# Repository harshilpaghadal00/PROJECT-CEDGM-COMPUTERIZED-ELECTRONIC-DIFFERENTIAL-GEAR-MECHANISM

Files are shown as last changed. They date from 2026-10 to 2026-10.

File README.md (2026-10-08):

# PROJECT CEDGM : COMPUTERIZED ELECTRONIC DIFFERENTIAL GEAR MECHANISM



Welcome to the **PROJECT CEDGM : COMPUTERIZED ELECTRONIC DIFFERENTIAL GEAR MECHANISM** project. This repository contains the complete suite of mechanical designs, electronic documentation, and firmware required to build, assemble, and run an Arduino-controlled Differential Gear Mechanism.

## Project Structure

The project is divided into three main subsystems:

### 1. Mechanical System (`01 - PROJECT CEDGM : COMPUTERIZED ELECTRONIC DIFFERENTIAL GEAR MECHANISM - MECHANICAL SYSTEM`)

Contains the CAD models for 3D printing and modification. Files are provided in `.f3d` (Fusion 360), `.step` (Standard 3D CAD), and `.stl` (Ready for 3D Printing) formats.

* **01 - Standard External Involute Miter Bevel Gear**
* **02 - T-Shape Standard External Involute Miter Bevel Gear Connector**
* **03 - 28BYJ-48 Stepper Motor (Mockup/Mount)**
* **04 - Primary Support Mechanism (Right Side)**
* **05 - Primary Support Mechanism (Left Side)**
* **06 - Differential Gear Mechanism** (Full assembly)
* **07 - Differential Gear Mechanism Base**

### 2. Electronic System (`02 - PROJECT CEDGM : COMPUTERIZED ELECTRONIC DIFFERENTIAL GEAR MECHANISM - ELECTRONIC SYSTEM`)

Contains all necessary datasheets and wiring documentation to safely build the circuit.

* **01 - 28BYJ-48 Stepper Motor Data Sheet**
* **02 - ULN2003 Stepper Motor Driver Data Sheet**
* **03 - Arduino UNO Data Sheet**
* **04 - Power Supply & Pin Configuration Documentation**

### 3. Embedded System & Software (`03 - PROJECT CEDGM : COMPUTERIZED ELECTRONIC DIFFERENTIAL GEAR MECHANISM - EMBEDDED SYSTEM & SOFTWARE`)

Contains the logic and control code for the microcontroller.

* **FINAL_FIRMWARE.ino**: The main Arduino sketch to upload to the board.
* **FIRMWARE FLOW.cpp**: A C++ file detailing the logic flow and algorithm of the firmware.

---

## 🛠️ Hardware Requirements

To build this project physically, you will need:

* 1x **Arduino UNO** (or compatible microcontroller)
* 1x (or more, as required) **28BYJ-48 Stepper Motor**
* 1x **ULN2003 Stepper Motor Driver Board**
* Appropriate **Power Supply** (Refer to the Power Supply Documentation in the Electronics folder)
* Jumper wires
* A 3D Printer and filament (PLA/PETG recommended) to print the mechanical parts.

---

## 🚀 Getting Started Guide

### Step 1: Mechanical Assembly

1. Locate the `.stl` files in the `01 - PROJECT CEDGM : COMPUTERIZED ELECTRONIC DIFFERENTIAL GEAR MECHANISM - MECHANICAL SYSTEM` folder.
2. Slice and 3D print the Base, Left/Right Support Mechanisms, Bevel Gears, and Connectors.
3. Assemble the printed parts. Use the Fusion 360 (`.f3d` or `.f3z`) files as a visual reference for how the components fit together.
4. Mount the **28BYJ-48 Stepper Motor** into the designated slot on the support mechanism.

### Step 2: Electronics Wiring

1. Connect the **28BYJ-48 Stepper Motor** to the **ULN2003 Driver Board**.
2. Open `04 - POWER SUPPLY & PIN CONFIGURATION DOCUMENTATION.pdf` in the Electronics folder to find the exact pin mapping.
3. Wire the ULN2003 Driver Board to the corresponding Digital I/O pins on the **Arduino UNO**.
4. Connect the power supply safely, ensuring the Arduino and the Motors receive appropriate voltage (do not draw stepper motor power directly from the Arduino's 5V pin if under heavy load).
5. Important: Use 5V - 2A Power Supply.

### Step 3: Software Setup & Flashing

1. Download and install the [Arduino IDE](https://www.arduino.cc/en/software).
2. Navigate to `03 - PROJECT CEDGM : COMPUTERIZED ELECTRONIC DIFFERENTIAL GEAR MECHANISM - EMBEDDED SYSTEM & SOFTWARE/FINAL_FIRMWARE/`.
3. Open `FINAL_FIRMWARE.ino` in the Arduino IDE.
4. Connect your Arduino UNO to your computer via USB.
5. In the Arduino IDE, go to **Tools > Board** and select "Arduino Uno".
6. Go to **Tools > Port** and select the appropriate COM port.
7. Click the **Upload** button to flash the firmware to the board.

### Step 4: Execution

Once the upload is complete and power is supplied, the Arduino will begin executing the logic defined in `FIRMWARE FLOW.cpp`, driving the stepper motor and actuating the differential gear mechanism.

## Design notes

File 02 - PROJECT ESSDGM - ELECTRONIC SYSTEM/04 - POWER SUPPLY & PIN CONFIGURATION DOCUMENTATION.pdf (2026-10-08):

From | To | Electronic Value | Description
Regulated DC Supply (+) | Central Star Positive Bus (+) | 5.0VDC (1.0A max) | Main positive DC feed from external supply.
Regulated DC Supply (-) | Central Star Ground Bus (-) | 0V / GND | Master ground return line for the entire system.
Central Star Positive Bus (+) | Decoupling Buffer (+) | 5.0VDC (470 uF || 100 nF) | High-frequency and transient voltage stabilization.
Central Star Ground Bus (-) | Decoupling Buffer (-) | 0V / GND | Return path for decoupling filter network.
Central Star Positive Bus (+) | Arduino UNO Pin +5V | 5.0VDC (~60 mA) | Direct ATmega328P logic board supply rail.
Central Star Ground Bus (-) | Arduino UNO Pin Gorund | 0V / GND | Digital logic reference ground return.
Central Star Positive Bus (+) | ULN2003 #1 Pin + | 5.0VDC (~180 mA max) | Driver 1 motor common and flyback diode power.
Central Star Ground Bus (-) | ULN2003 #1 Pin - | 0V / GND | Driver 1 Darlington emitter ground return.
Central Star Positive Bus (+) | ULN2003 #2 Pin + | 5.0VDC (~180 mA max) | Driver 2 motor common and flyback diode power.

Central Star Ground Bus (-) | ULN2003 #2 Pin - | 0V / GND | Driver 2 Darlington emitter ground return.
ULN2003 #1 Jumper Pin A | ULN2003 #1 Jumper Pin B | 0 Ohm Shunt | Connects +5V to Pin 9 clamp diodes and LEDs.
ULN2003 #2 Jumper Pin A | ULN2003 #2 Jumper Pin B | 0 Ohm Shunt | Connects +5V to Pin 9 clamp diodes and LEDs.
Central Star Positive Bus (+) | 10k Resistor Lead 1 | 5.0VDC | Bias source for hardware interrupt pull-up.
10k Resistor Lead 2 | Arduino UNO Pin D2 (INT0) | 5.0VDC / 10 kOhm | Holds interrupt pin HIGH when the button is open.
Arduino UNO Pin D2 | Push Button Terminal 1 | 5.0V / 0V Logic | Routes active-LOW trigger on button press.
Push Button Terminal 2 | Central Star Ground Bus (-) | 0V / GND | Ground reference completing switch closure.
Arduino UNO Pin D2 | 100nF Cap Lead 1 | 100 nF Filter | Shunts mechanical contact bounce to ground.
100nF Cap Lead 2 | Central Star Ground Bus (-) | 0V / GND | Ground return for RC debounce filter network.
Arduino UNO Pin D10 | ULN2003 #1 Pin IN1 | 5.0V Logic (~1.3 mA) | Logic drive for Motor 1 Phase A.
Arduino UNO Pin D3 | ULN2003 #1 Pin IN2 | 5.0V Logic (~1.3 mA) | Logic drive for Motor 1 Phase B.

Arduino UNO Pin D4 | ULN2003 #1 Pin IN3 | 5.0V Logic (~1.3 mA) | Logic drive for Motor 1 Phase C.
Arduino UNO Pin D5 | ULN2003 #1 Pin IN4 | 5.0V Logic (~1.3 mA) | Logic drive for Motor 1 Phase D.
Arduino UNO Pin D6 | ULN2003 #2 Pin IN1 | 5.0V Logic (~1.3 mA) | Logic drive for Motor 2 Phase A.
Arduino UNO Pin D7 | ULN2003 #2 Pin IN2 | 5.0V Logic (~1.3 mA) | Logic drive for Motor 2 Phase B.
Arduino UNO Pin D8 | ULN2003 #2 Pin IN3 | 5.0V Logic (~1.3 mA) | Logic drive for Motor 2 Phase C.
Arduino UNO Pin D9 | ULN2003 #2 Pin IN4 | 5.0V Logic (~1.3 mA) | Logic drive for Motor 2 Phase D.
ATmega328P Pin PB5 (D13) | Built-in LED (LED_BUILTIN) | 5.0V (~5.6 mA) | Onboard PCB trace driving interrupt status LED.
ULN2003 #1 JST Pin 1 | Motor 1 Blue Wire | Switched GND (~85 mA) | Low-side sink for Motor 1 Phase A coil.
ULN2003 #1 JST Pin 2 | Motor 1 Pink Wire | Switched GND (~85 mA) | Low-side sink for Motor 1 Phase B coil.
ULN2003 #1 JST Pin 3 | Motor 1 Yellow Wire | Switched GND (~85 mA) | Low-side sink for Motor 1 Phase C coil.
ULN2003 #1 JST | Motor 1 Orange | Switched GND (~85 | Low-side sink for

Pin 4 | Wire | mA) | Motor 1 Phase D coil.
ULN2003 #1 JST Pin 5 | Motor 1 Red Wire | 5.0VDC (~180 mA max) | Common center-tap +5V feed for Motor 1 coils.
ULN2003 #2 JST Pin 1 | Motor 2 Blue Wire | Switched GND (~85 mA) | Low-side sink for Motor 2 Phase A coil.
ULN2003 #2 JST Pin 2 | Motor 2 Pink Wire | Switched GND (~85 mA) | Low-side sink for Motor 2 Phase B coil.
ULN2003 #2 JST Pin 3 | Motor 2 Yellow Wire | Switched GND (~85 mA) | Low-side sink for Motor 2 Phase C coil.
ULN2003 #2 JST Pin 4 | Motor 2 Orange Wire | Switched GND (~85 mA) | Low-side sink for Motor 2 Phase D coil.
ULN2003 #2 JST Pin 5 | Motor 2 Red Wire | 5.0VDC (~180 mA max) | Common center-tap +5V feed for Motor 2 coils.

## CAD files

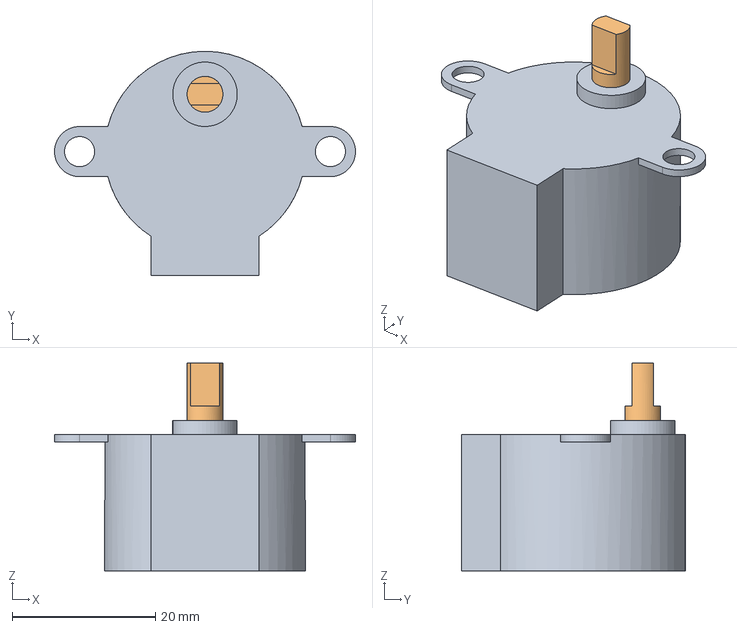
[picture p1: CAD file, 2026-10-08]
01 - PROJECT ESSDGM - MECHANICAL SYSTEM/03 - 28BYJ-48 STEPPER MOTOR.step
42.0 x 31.3 x 29.0 mm
01 - 28BYJ-48 STEPPER MOTOR BASE
02 - 28BYJ-48 STEPPER MOTOR SHAFT

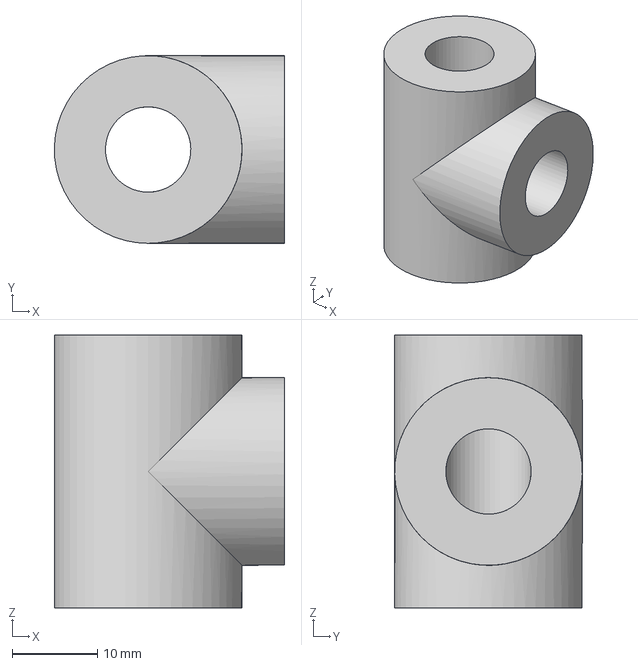
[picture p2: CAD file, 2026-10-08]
01 - PROJECT ESSDGM - MECHANICAL SYSTEM/02 - T-SHAPE STANDARD EXTERNAL INVOLUTE MITER BEVEL GEAR CONNECTOR.step
27.0 x 22.0 x 32.0 mm

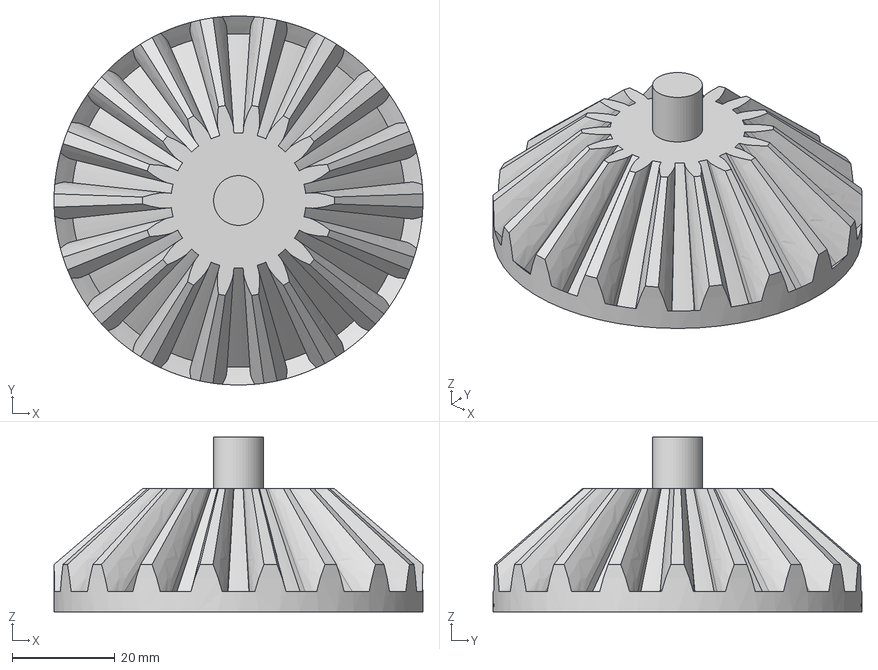
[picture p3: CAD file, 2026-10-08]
01 - PROJECT ESSDGM - MECHANICAL SYSTEM/01 - STANDARD EXTERNAL INVOLUTE MITER BEVEL GEAR.step
71.8 x 71.8 x 34.0 mm

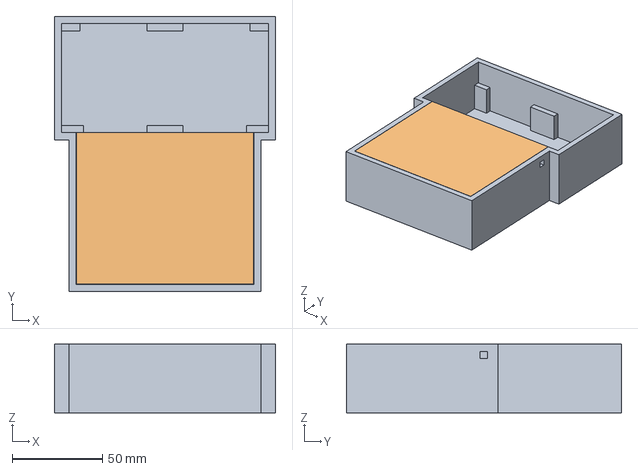
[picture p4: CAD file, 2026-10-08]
01 - PROJECT ESSDGM - MECHANICAL SYSTEM/07 - DIFFERENTIALGEAR MECHANISM BASE.step
122.3 x 152.3 x 38.0 mm
01 - DIFFERENTIAL GEAR MECHANISM BASE
02 - DIFFERENTIAL GEAR MECHANISM CAP

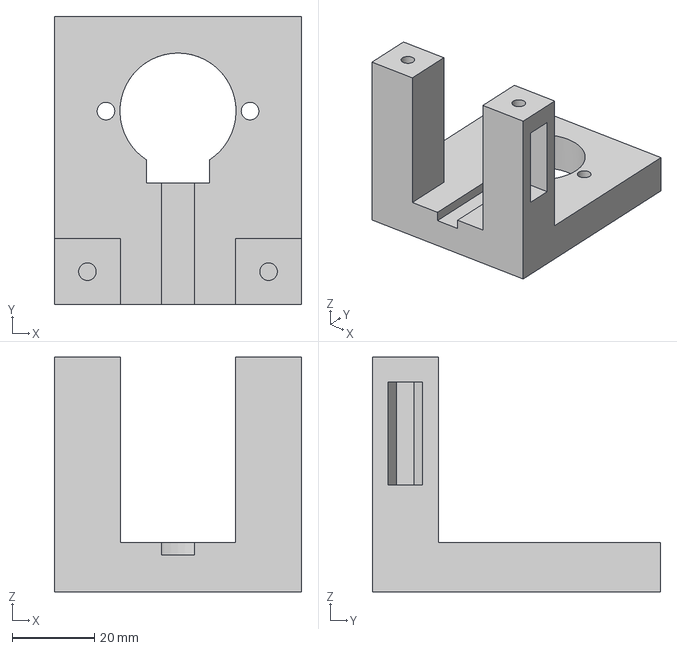
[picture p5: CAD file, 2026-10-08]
01 - PROJECT ESSDGM - MECHANICAL SYSTEM/05 - PRIMARY SUPPORT MECHANISM ( LEFT SIDE ).step
60.0 x 70.0 x 57.0 mm

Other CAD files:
01 - PROJECT ESSDGM - MECHANICAL SYSTEM/04 - PRIMARY SUPPORT MECHANISM ( RIGHT SIDE ).step
01 - PROJECT ESSDGM - MECHANICAL SYSTEM/01 - STANDARD EXTERNAL INVOLUTE MITER BEVEL GEAR.f3d
01 - PROJECT ESSDGM - MECHANICAL SYSTEM/01 - STANDARD EXTERNAL INVOLUTE MITER BEVEL GEAR.stl
01 - PROJECT ESSDGM - MECHANICAL SYSTEM/02 - T-SHAPE STANDARD EXTERNAL INVOLUTE MITER BEVEL GEAR CONNECTOR.f3d
01 - PROJECT ESSDGM - MECHANICAL SYSTEM/02 - T-SHAPE STANDARD EXTERNAL INVOLUTE MITER BEVEL GEAR CONNECTOR.stl
01 - PROJECT ESSDGM - MECHANICAL SYSTEM/03 - 28BYJ-48 STEPPER MOTOR.f3d
01 - PROJECT ESSDGM - MECHANICAL SYSTEM/03 - 28BYJ-48 STEPPER MOTOR.stl
01 - PROJECT ESSDGM - MECHANICAL SYSTEM/04 - PRIMARY SUPPORT MECHANISM ( RIGHT SIDE ).f3d
01 - PROJECT ESSDGM - MECHANICAL SYSTEM/04 - PRIMARY SUPPORT MECHANISM ( RIGHT SIDE ).stl
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

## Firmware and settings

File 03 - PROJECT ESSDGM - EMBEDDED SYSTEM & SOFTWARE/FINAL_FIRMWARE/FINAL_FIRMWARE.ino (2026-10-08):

#include <math.h>

// VARIABLE DECLARATIONS RELATED TO PHASES
#define PHASE_1 1 // LEFT MOTOR CALIBRATION PHASE
#define PHASE_2 2 // RIGHT MOTOR CALIBRATION PHASE
#define PHASE_3 3 // WAITING PHASE
#define PHASE_4 4 // DIFFERENT MOTION DEMONSTRATION PHASE
#define PHASE_5 5 // WAITING PHASE
volatile byte X_EXECUTION_PHASE = PHASE_1;

// VARIABLE DECLARATIONS RELATED TO INTERRUPT
#define INTERRUPT_PIN 2
const byte X_INTERRUPT_PIN = INTERRUPT_PIN;

// INTERRUPT SERVICE ROUTINE DECLARATION
void X_CHANGE_EXECUTION_PHASE();

// DIFFERENT CALIBRATION METHOD DEFINITIONS
void X_LEFT_MOTOR_CALIBRATION();
void X_RIGHT_MOTOR_CALIBRATION();

// DIFFERENT MOTION DEMONSTRATION METHOD DECLARATIONS
void X_DEMONSTRATE_ONE_LOCKED_ONE_DRVE(); // EPICYCLIC MOTION
void X_DEMONSTRATE_SAME_RPM_SAME_DIRECTION(); // PURE PITCH MOTION
void X_DEMONSTRATE_SAME_RPM_OPPOSITE_DIRECTION(); // PURE ROLL MOTION

// DEBOUNCE TUNING CONSTANT
const unsigned long X_DEBOUNCE_DELAY_MS = 25;

// MOTOR DRIVER PIN DECLARATIONS

// MOTOR 1 (LEFT)  -> ULN2003 #1 -> 28BYJ-48 #1
const byte M1_IN1 = 10; // Motor 1 Phase A
const byte M1_IN2 = 3;  // Motor 1 Phase B
const byte M1_IN3 = 4;  // Motor 1 Phase C
const byte M1_IN4 = 5;  // Motor 1 Phase D

// MOTOR 2 (RIGHT) -> ULN2003 #2 -> 28BYJ-48 #2
const byte M2_IN1 = 6;  // Motor 2 Phase A
const byte M2_IN2 = 7;  // Motor 2 Phase B
const byte M2_IN3 = 8;  // Motor 2 Phase C
const byte M2_IN4 = 9;  // Motor 2 Phase D

// ---------------------------------------------------
static const byte HALF_STEP_SEQUENCE[8][4] = {
  {1, 0, 0, 0},
  {1, 1, 0, 0},
  {0, 1, 0, 0},
  {0, 1, 1, 0},
  {0, 0, 1, 0},
  {0, 0, 1, 1},
  {0, 0, 0, 1},
  {1, 0, 0, 1}
};
static const double STEPS_PER_OUTPUT_REVOLUTION = 4075.7728;
static const byte MIN_SAFE_RPM = 1;
static const byte MAX_SAFE_RPM = 10;
static const bool M1_INVERT_DIRECTION = false;
static const bool M2_INVERT_DIRECTION = false;
static int M1_HALFSTEP_INDEX = 0;
static int M2_HALFSTEP_INDEX = 0;
void rotate_motors_simultaneously(byte m1_direction, byte m1_rotation_angle, byte m1_rpm, byte m2_direction, byte m2_rotation_angle, byte m2_rpm);

// ---------------------------------------------------

// INITIALIZATION SETUP METHOD
void setup() {

  // INTERRUPT RELATED INITIALIZATION
  pinMode(X_INTERRUPT_PIN, INPUT);
  attachInterrupt(digitalPinToInterrupt(X_INTERRUPT_PIN), X_CHANGE_EXECUTION_PHASE, FALLING);
  
  // PHASE INDICATOR LED INITIALIZATION
  pinMode(LED_BUILTIN, OUTPUT);

  // MOTOR 1 (LEFT) DRIVER INITIALIZATION
  pinMode(M1_IN1, OUTPUT); digitalWrite(M1_IN1, LOW);
  pinMode(M1_IN2, OUTPUT); digitalWrite(M1_IN2, LOW);
  pinMode(M1_IN3, OUTPUT); digitalWrite(M1_IN3, LOW);
  pinMode(M1_IN4, OUTPUT); digitalWrite(M1_IN4, LOW);

  // MOTOR 2 (RIGHT) DRIVER INITIALIZATION
  pinMode(M2_IN1, OUTPUT); digitalWrite(M2_IN1, LOW);
  pinMode(M2_IN2, OUTPUT); digitalWrite(M2_IN2, LOW);
  pinMode(M2_IN3, OUTPUT); digitalWrite(M2_IN3, LOW);
  pinMode(M2_IN4, OUTPUT); digitalWrite(M2_IN4, LOW);
}

// LOOPING LOOP METHOD
void loop() {

  // PHASE SELECTOR SWITCH CASE
  switch (X_EXECUTION_PHASE) {
    
    case PHASE_1:
      digitalWrite(LED_BUILTIN, HIGH);
      X_LEFT_MOTOR_CALIBRATION();
      digitalWrite(LED_BUILTIN, LOW);
      delay(1000);
      break;

    case PHASE_2:
      digitalWrite(LED_BUILTIN, HIGH);
      X_RIGHT_MOTOR_CALIBRATION();
      digitalWrite(LED_BUILTIN, LOW);
      delay(1000);
      break;
      
    case PHASE_3:
      digitalWrite(LED_BUILTIN, HIGH);
      break;
    
    case PHASE_4:
      digitalWrite(LED_BUILTIN, LOW);
      X_DEMONSTRATE_ONE_LOCKED_ONE_DRVE();
      X_DEMONSTRATE_SAME_RPM_SAME_DIRECTION();
      X_DEMONSTRATE_SAME_RPM_OPPOSITE_DIRECTION();
      X_EXECUTION_PHASE = PHASE_5;
      break;
    
    case PHASE_5:
      digitalWrite(LED_BUILTIN, HIGH);
      break;

    default:
      X_EXECUTION_PHASE = PHASE_1;
      break;
  }
  
}

// INTERRUPT SERVICE ROUTINE DEFINITION
void X_CHANGE_EXECUTION_PHASE() {
  static unsigned long X_LAST_INTERRUPT_TIME = 0;
  unsigned long X_NOW = millis();
  if (X_NOW - X_LAST_INTERRUPT_TIME > X_DEBOUNCE_DELAY_MS) X_EXECUTION_PHASE = (X_EXECUTION_PHASE % 5) + 1;
  X_LAST_INTERRUPT_TIME = X_NOW;
}

// DIFFERENT CALIBRATION METHOD DEFINITIONS

// LEFT MOTOR CALIBRATION
void X_LEFT_MOTOR_CALIBRATION() {
  rotate_motors_simultaneously(1, 2, 6, 0, 0, 6);
  return;
}

// RIGHT MOTOR CALIBRATION
void X_RIGHT_MOTOR_CALIBRATION() {
  rotate_motors_simultaneously(1, 0, 6, 0, 2, 6);
  return;
}

// DIFFERENT MOTION DEMONSTRATION METHOD DEFINITIONS

// EPICYCLIC MOTION
void X_DEMONSTRATE_ONE_LOCKED_ONE_DRVE() {
  rotate_motors_simultaneously(1, 30, 6, 0, 0, 6);
  rotate_motors_simultaneously(1, 30, 6, 0, 0, 6);
  rotate_motors_simultaneously(0, 90, 6, 0, 0, 6);
  rotate_motors_simultaneously(0, 30, 6, 0, 0, 6);
  rotate_motors_simultaneously(1, 30, 6, 0, 0, 6);
  rotate_motors_simultaneously(1, 30, 6, 0, 0, 6);
  return;
}

// PURE PITCH MOTION
void X_DEMONSTRATE_SAME_RPM_SAME_DIRECTION() {
  rotate_motors_simultaneously(1, 30, 6, 0, 30, 6);
  rotate_motors_simultaneously(1, 30, 6, 0, 30, 6);
  rotate_motors_simultaneously(0, 90, 6, 1, 90, 6);
  rotate_motors_simultaneously(0, 30, 6, 1, 30, 6);
  rotate_motors_simultaneously(1, 30, 6, 0, 30, 6);
  rotate_motors_simultaneously(1, 30, 6, 0, 30, 6);
  return;
}

// PURE ROLL MOTION
void X_DEMONSTRATE_SAME_RPM_OPPOSITE_DIRECTION() {
  rotate_motors_simultaneously(1, 30, 6, 1, 30, 6);
  rotate_motors_simultaneously(1, 30, 6, 1, 30, 6);
  rotate_motors_simultaneously(0, 90, 6, 0, 90, 6);
  rotate_motors_simultaneously(0, 30, 6, 0, 30, 6);
  rotate_motors_simultaneously(1, 30, 6, 1, 30, 6);
  rotate_motors_simultaneously(1, 30, 6, 1, 30, 6);
  return;
}

// -------------------------------------------------

void rotate_motors_simultaneously(byte m1_direction, byte m1_rotation_angle, byte m1_rpm, byte m2_direction, byte m2_rotation_angle, byte m2_rpm) {

  m1_direction = (m1_direction == 1) ? 1 : 0;
  m2_direction = (m2_direction == 1) ? 1 : 0;

  if (m1_rotation_angle > 90) m1_rotation_angle = 90;
  if (m2_rotation_angle > 90) m2_rotation_angle = 90;

  if (m1_rpm < MIN_SAFE_RPM) m1_rpm = MIN_SAFE_RPM;
  if (m1_rpm > MAX_SAFE_RPM) m1_rpm = MAX_SAFE_RPM;
  if (m2_rpm < MIN_SAFE_RPM) m2_rpm = MIN_SAFE_RPM;
  if (m2_rpm > MAX_SAFE_RPM) m2_rpm = MAX_SAFE_RPM;

  unsigned int m1_target_steps = (unsigned int) round((double) m1_rotation_angle / 360.0 * STEPS_PER_OUTPUT_REVOLUTION);
  unsigned int m2_target_steps = (unsigned int) round((double) m2_rotation_angle / 360.0 * STEPS_PER_OUTPUT_REVOLUTION);

  unsigned long m1_step_interval_us = (unsigned long) (60000000.0 / ((double) m1_rpm * STEPS_PER_OUTPUT_REVOLUTION));
  unsigned long m2_step_interval_us = (unsigned long) (60000000.0 / ((double) m2_rpm * STEPS_PER_OUTPUT_REVOLUTION));

  unsigned int m1_steps_done = 0;
  unsigned int m2_steps_done = 0;
  unsigned long m1_last_step_time = micros();
  unsigned long m2_last_step_time = micros();

  while (m1_steps_done < m1_target_steps || m2_steps_done < m2_target_steps) {

    unsigned long now = micros();

    if (m1_steps_done < m1_target_steps && (now - m1_last_step_time) >= m1_step_interval_us) {
      bool m1_effective_dir = m1_direction;
      if (M1_INVERT_DIRECTION) m1_effective_dir = !m1_effective_dir;

      M1_HALFSTEP_INDEX = m1_effective_dir ? (M1_HALFSTEP_INDEX + 1) % 8 : (M1_HALFSTEP_INDEX + 7) % 8;
      digitalWrite(M1_IN1, HALF_STEP_SEQUENCE[M1_HALFSTEP_INDEX][0]);
      digitalWrite(M1_IN2, HALF_STEP_SEQUENCE[M1_HALFSTEP_INDEX][1]);
      digitalWrite(M1_IN3, HALF_STEP_SEQUENCE[M1_HALFSTEP_INDEX][2]);
      digitalWrite(M1_IN4, HALF_STEP_SEQUENCE[M1_HALFSTEP_INDEX][3]);

      m1_steps_done++;
      m1_last_step_time = now;
    }

    now = micros();
    if (m2_steps_done < m2_target_steps && (now - m2_last_step_time) >= m2_step_interval_us) {
      bool m2_effective_dir = m2_direction;
      if (M2_INVERT_DIRECTION) m2_effective_dir = !m2_effective_dir;

      M2_HALFSTEP_INDEX = m2_effective_dir ? (M2_HALFSTEP_INDEX + 1) % 8 : (M2_HALFSTEP_INDEX + 7) % 8;
      digitalWrite(M2_IN1, HALF_STEP_SEQUENCE[M2_HALFSTEP_INDEX][0]);
      digitalWrite(M2_IN2, HALF_STEP_SEQUENCE[M2_HALFSTEP_INDEX][1]);
      digitalWrite(M2_IN3, HALF_STEP_SEQUENCE[M2_HALFSTEP_INDEX][2]);
      digitalWrite(M2_IN4, HALF_STEP_SEQUENCE[M2_HALFSTEP_INDEX][3]);

      m2_steps_done++;
      m2_last_step_time = now;
    }
  }

  digitalWrite(M1_IN1, LOW); digitalWrite(M1_IN2, LOW); digitalWrite(M1_IN3, LOW); digitalWrite(M1_IN4, LOW);
  digitalWrite(M2_IN1, LOW); digitalWrite(M2_IN2, LOW); digitalWrite(M2_IN3, LOW); digitalWrite(M2_IN4, LOW);

}

// -------------------------------------------------
